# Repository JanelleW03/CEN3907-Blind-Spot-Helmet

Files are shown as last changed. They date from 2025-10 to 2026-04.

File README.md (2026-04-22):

# CEN4908-Blind-Spot-Helmet
Urban cyclists face safety risks from traffic and limited visibility. Traditional helmets protect the head but don’t enhance awareness. The Blind Spot Helmet uses radar-based detection and haptic feedback to alert riders of nearby vehicles in real time, improving safety for daily commuters on busy streets.

At a high level, our current architecture for this project is as follows. We utilize a Raspberry Pi 4 to poll two LiDAR sensors and interpret if there are any objects present within a predetermined range that could pose a risk to the user. If the LiDARs identify a potentially dangerous object, a haptic feedback sensor will be activated on the side that the object was detected to alert the user of its presence.

# Completed Work
We developed fully functioning code for the Pi 4 that polls the LiDAR sensors and successfully triggers haptic feedback on the side where an object was detected. 

In parallel, we are working on an implementation for the Raspberry Pi Pico, which is much more portable and consumes less power. At this point, we are currently testing LiDAR integration with Pico-specific code.

As for physical components within the project, we have gone through many iterations of 3d modules to house our system. The current one is robust and houses the Raspberry Pi as well as the sensors connected to it, with cutouts for charging and wiring.

# Known Bugs
The only main bug we have for our design at the moment is due to the physical connections between Raspberry Pi and sensors. Because we haven't soldered connections, as we are still testing multiple systems, our wiring is liable to disconnections during movement testing. This will be fixed once we have finalized our design and implement permanent connections.

# Onshape Design of Helmet Module
Copy and past this link into your browser to view:
https://cad.onshape.com/documents/718453d0fac994bf19ba09c7/w/0e19fb7305c1e5489b3984cd/e/3690a92add8a8350898fd115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

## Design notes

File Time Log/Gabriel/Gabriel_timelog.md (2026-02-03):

# Gabriel Timelog for Design II

## 01/19 - Team Meeting
### 2 hrs
- Discussed plan for the semester
- Divided work for the alpha build
- I was tasked with getting us back to where we were last semester, since we had our work erased and had a fresh sd card for the pi
- Initial environment setup for the pi

## 01/20 - Pi ML Camera Debug Session
## 5 hrs
- Had this debug session to get us back to where we were last semester
- Found out that there were some bugs regarding versions of different requirements for the ML camera script
- The most pressing issue was numpy version, which took me a while to figure out
- Removed custom numpy installation from python venv and defaulted to the default numpy system installation (version 1.19.5)

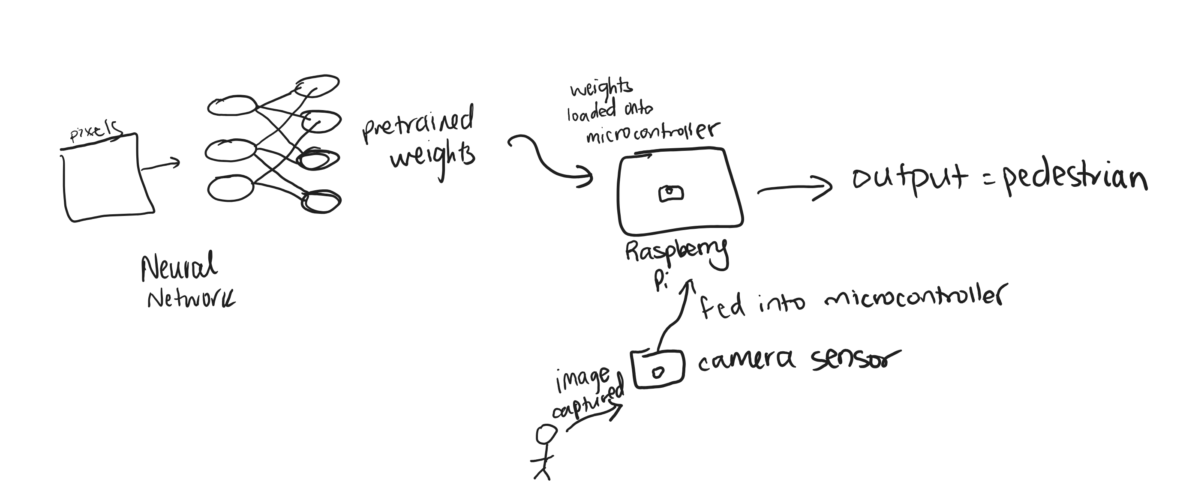
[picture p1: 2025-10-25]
cv_design.png

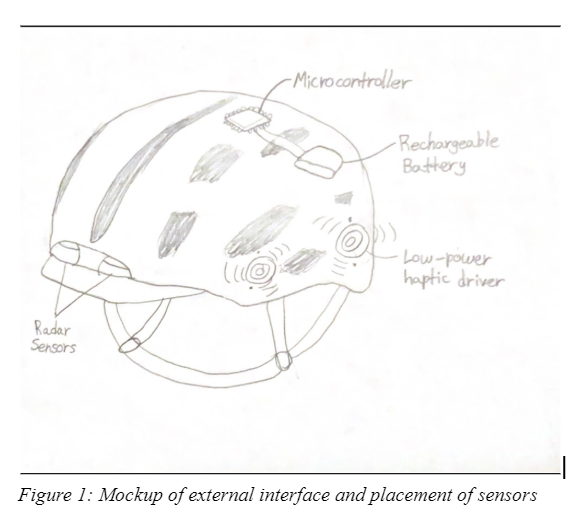
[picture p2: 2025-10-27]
Helmet Mockup.png

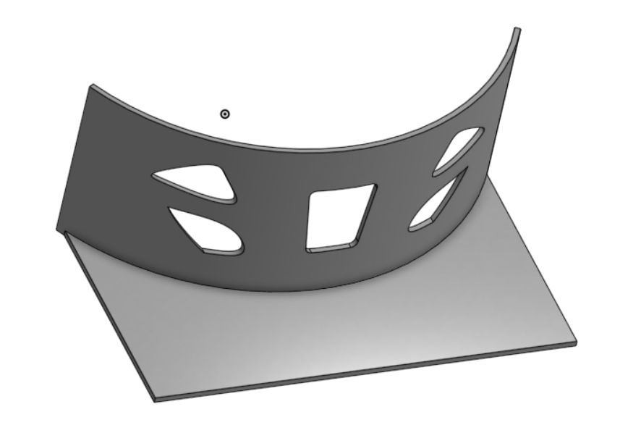
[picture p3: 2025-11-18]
Helmet Module Prototype.png

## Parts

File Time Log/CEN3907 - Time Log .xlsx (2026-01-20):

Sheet: Emily
Date | Time In | Time Out | Description of Work | Total Time
2025-10-01 | 0.4583333333 | 0.6458333333 | Research on components, primarily microprocessor and camera sensor | 4
2025-10-02 | 0.5833333333 | 0.7083333333 | Research on similar projects and integration techniques | 3
2025-10-07 | 0.4791666667 | 0.5 | Check in meeting 1, discussed design draft | 0.5
2025-10-09 | 0.5 | 0.5416666667 | Discussion with team on feedback from design draft, ideas on how to implement | 1
2025-10-14 | 0.4791666667 | 0.5208333333 | Check in meeting 2, discussed improvements for final design plan | 0.5
2025-10-17 | 0.5416666667 | 0.625 | Team meeting, compiled research on possible components, discussed | 2 | 46
2025-10-23 | 0.4791666667 | 0.5208333333 | Check in meeting 3, reviewed possible parts list | 1
2025-10-23 | 0.6666666667 | 0.7083333333 | Reviewed tinkercad for pre alpha build | 1
2025-10-24 | 0.5416666667 | 0.6666666667 | Researched haptic feedback articles to address user friendliness | 3
2025-10-25 | 0.625 | 0.7708333333 | Created simple CNN for car detection | 3.5
2025-11-04 | 23:30:00 | 13:00:00 | Check in meeting 5, ordered Raspberry Pi, camera attachment for Raspberry Pi, and webcam in case; discussed plan to meet for Raspberry Pi and camera setup | 1.5
2025-11-07 | 13:00:00 | 16:00:00 | Gathered materials; set up Raspberry Pi and camera module; created simple script to make sure pictures/videos could be taken | 3
2025-11-11 | 12:30:00 | 16:00:00 | Met with team and emailed stakeholder in lieu of Check in meeting 6; trained and tested ML model for vehicle image dataset | 3.5
2025-11-13 | 23:00:00 | 15:30:00 | Met with team and started working on the Onshape prototype for the helmet attachment. | 4.5
2025-11-13 | 18:00:00 | 20:00:00 | Worked on the documentation for the Prototype Report | 2
2025-11-14 | 14:30:00 | 17:30:00 | continued working on the onshape prototype | 3
2025-11-15 | 11:00:00 | 15:00:00 | finished working on the OnShape Prototype | 4
2025-11-16 | 13:30:00 | 17:00:00 | Worked on the documentation for the Prototype Report | 3.5
2025-11-16 | 21:30:00 | 23:00:00 | Worked on the documentation for the Prototype Report | 1.5

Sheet: Gabriel
Date | Time In | Time Out | Description of Work | Time
2025-10-01 | 0.5416666667 | 0.6666666667 | Researched possible parts that can be used in our design | 3
2025-10-03 | 0.375 | 0.4375 | Looked into haptic sensors/piezos and what could fit our product | 1.5
2025-10-07 | 0.4791666667 | 0.5 | Check in meeting 1, discussed design draft | 0.5
2025-10-09 | 0.5 | 0.5416666667 | Discussion with team on feedback from design draft, ideas on how to implement | 1
2025-10-10 | 0.5833333333 | 0.7083333333 | Began studying ML via online tutorials and youtube videos | 3
2025-10-12 | 0.7083333333 | 0.75 | Researched different cameras that we could use for ML | 1
2025-10-14 | 0.4791666667 | 0.5208333333 | Check in meeting 2, discussed improvements for final design plan | 1 | Total Time
2025-10-15 | 0.7083333333 | 0.8541666667 | Continued studying basic ML for the camera portion of our design | 3.5
2025-10-17 | 0.5416666667 | 0.6666666667 | Team meeting, compiled research on possible components, discussed | 3 | 46.5
2025-10-20 | 0.6666666667 | 0.7708333333 | Further researched ML for camera vision | 2.5
2025-10-23 | 0.4791666667 | 0.5208333333 | Check in meeting 3, reviewed possible parts list | 1
2025-10-25 | 18:00:00 | 20:30:00 | Researched object detection examples in Raspberry Pi as well as pre-trained models (Tensorflow) | 2.5
2025-10-28 | 11:00:00 | 12:30:00 | Check in meeting 4; afterwards discussed purchase of components | 1.5
2025-11-02 | 17:00:00 | 19:00:00 | Meeting with team, discussed work assignments and researched technical work to be completed | 2
2025-11-04 | 11:00:00 | 12:30:00 | Check in meeting 5; ordered Raspberry Pi, camera, and haptic sensors | 1.5
2025-11-07 | 11:00:00 | 13:00:00 | Set up radar sensor with Arduino; got it to detect presence | 3
2025-11-07 | 13:00:00 | 16:00:00 | Set up Raspberry Pi OS, configured camera, and took photos and videos with it to assess functionality | 3
2025-11-11 | 13:00:00 | 16:00:00 | Met with team; mostly worked on configuring remote access to Raspberry Pi via SSH | 3
2025-11-13 | 0.4895833333 | 0.7708333333 | Configured object detection on camera and got it working | 6.75
2025-11-17 | 0.4166666667 | 0.5104166667 | Created script to automatically set up camera on new raspi images | 2.25

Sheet: Devika
Date | Time In | Time Out | Description of Work | Total Time
2025-10-01 | 0.4583333333 | 0.6041666667 | Research on components, primarily microprocessor and camera sensor | 3.5
2025-10-02 | 0.5833333333 | 0.7083333333 | Research on textbook about computer vision with Raspberry Pi, read some of book | 3
2025-10-07 | 0.4791666667 | 0.5 | Check in meeting 1, discussed design draft | 0.5
2025-10-09 | 0.5 | 0.5416666667 | Discussion with team on feedback from design draft, ideas on how to implement | 1
2025-10-14 | 0.4791666667 | 0.5208333333 | Check in meeting 2, discussed improvements for final design plan | 0.5
2025-10-17 | 0.5416666667 | 0.6666666667 | Team meeting, compiled research on possible components, discussed | 3 | Total Time:
2025-10-23 | 0.4791666667 | 0.5208333333 | Check in meeting 3, reviewed possible parts list | 1 | 47.25
2025-10-23 | 0.6666666667 | 0.7083333333 | Reviewed tinkercad for pre alpha build | 1
2025-10-24 | 0.5416666667 | 0.6666666667 | Researched and found Kaggle dataset for car detection, yolo code for image recognition | 3
2025-10-25 | 0.625 | 0.7708333333 | Created simple CNN for car detection | 3.5
2025-10-28 | 11:00:00 | 12:30:00 | Check in meeting 4, discussed with team after to purchase parts | 1.5
2025-11-02 | 17:00:00 | 19:00:00 | Meeting with team, discussed work assignments and researched technical work to be completed | 2
2025-11-04 | 11:00:00 | 12:30:00 | Check in meeting 5, ordered Raspberry Pi, camera, and haptic sensors | 1.5
2025-11-07 | 11:00:00 | 13:00:00 | Set up radar sensor with Arduino, wrote code to communicate through UART to detect presence | 3
2025-11-07 | 13:00:00 | 16:00:00 | Set up Raspberry Pi OS, configured camera, wrote Python script to record videos and take photos to prove camera functionality | 3
2025-11-09 | 19:00:00 | 22:00:00 | Updated the CNN, used a simpler architecture, wrote code to preprocess image dataset and trained model | 3
2025-11-11 | 10:00:00 | 11:30:00 | Wrote email in lieu of check in 6, updating professor on work the team completed and will present for prototype | 1.5
2025-11-11 | 13:00:00 | 16:00:00 | Met with team to continue working on prototype report, slides, and found example model to download on Raspberry Pi | 3
2025-11-11 | 17:00:00 | 19:00:00 | Researched converting Pytorch CNN model to tflite format for Raspberry Pi, started writing code to convert model | 2
2025-11-13 | 11:45:00 | 14:00:00 | Connected radar sensor to rest of sensors (LED, piezo, and haptic), updated Arduino code to have total interaction | 2.25
2025-11-13 | 14:00:00 | 15:30:00 | Updated Raspberry Pi OS to be compatible with popular ML models, downloaded example model for object detection | 1.5
2025-11-16 | 15:00:00 | 18:00:00 | Double checked functionality of Raspberry Pi with downloaded model, and radar sensor-piezo setup, practice demo | 3

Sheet: Janelle
Date | Start Time | End Time | Duration | Summary of Tasks Completed
2025-10-01 | 0.4583333333 | 0.6041666667 | 3.50 | Research on components, primarily microprocessor and camera sensor
2025-10-02 | 0.5833333333 | 0.7083333333 | 3.00 | Research on textbook about computer vision with Raspberry Pi
2025-10-07 | 0.4791666667 | 0.5208333333 | 1.00 | Check in meeting 1, discussed design draft
2025-10-09 | 0.5 | 0.5416666667 | 1.00 | Discussion with team on feedback from design draft, ideas on how to implement
2025-10-14 | 0.4791666667 | 0.5208333333 | 1.00 | Check in meeting 2, discussed improvements for final design plan
2025-10-17 | 0.5416666667 | 0.6666666667 | 3.00 | Team meeting, compiled research on possible components, discussed
2025-10-23 | 0.4791666667 | 0.5625 | 2.00 | Check in meeting 3, reviewed possible parts list
2025-10-23 | 0.7916666667 | 0.875 | 4.00 | Designed and built tinkercad demo with code
2025-10-23 | 0.6666666667 | 0.75 | 2 | Reviewed tinkercad for pre alpha build
2025-10-24 | 0.5416666667 | 0.6666666667 | 3 | Researched and found Kaggle dataset for car detection, yolo code for image recognition
2025-10-25 | 0.625 | 0.7708333333 | 3.5 | Created simple CNN for car detection
2025-10-28 | 11:00:00 | 12:30:00 | 1.5 | Check in meeting 4, discussed with team after to purchase parts
2025-11-02 | 17:00:00 | 19:00:00 | 2 | discussed work assignments and any parts we still need to order
2025-11-04 | 11:00:00 | 12:30:00 | 1.5 | Check in meeting 5, ordered Raspberry Pi, camera, and haptic sensors
2025-11-04 | 11:00:00 | 13:00:00 | 2.00 | team meeting, compiled research on possible components, discussed
2025-11-05 | 11:00:00 | 14:00:00 | 3 | team meeting to test radar sensor
2025-11-11 | 10:00:00 | 11:30:00 | 1.5 | Wrote email in lieu of check in 6, updating stakeholder on work the team completed and will present for prototype
2025-11-11 | 15:00:00 | 17:00:00 | 2.00 | integrated radar with distance sensor
2025-11-14 | 10:00:00 | 12:00:00 | 2.00 | switched radar sensor serial so that it works faster and detects more accurate with the arduino
2025-11-15 | 10:00:00 | 12:00:00 | 2 | worked with arduino and make the connections more organized to a smaller breadboard
2025-11-16 | 15:00:00 | 17:00:00 | 2.00 | practiced demo and slides for presentation
 |  |  | 46.50

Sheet: Ana
Date | Time In | Time Out | Description of Work | Total Time
2025-10-01 | 19:30:00 | 22:00:00 | Researched existing solutions to cycling problem and ways to differentiate solution with our product | 2.5
2025-10-02 | 17:30:00 | 21:00:00 | Researched hardware components for helmet (potential sensors) | 2.5
2025-10-05 | 12:00:00 | 15:30:00 | Researched CNN model for image recognition and potential datasets to use for image detection | 3.5
2025-10-07 | 11:30:00 | 12:00:00 | Check in meeting 1, discussed design draft | 0.5
2025-10-09 | 12:00:00 | 13:00:00 | Discussion with team on feedback from design draft, ideas on how to implement | 1
2025-10-14 | 11:30:00 | 12:30:00 | Check in meeting 2, discussed improvements for final design plan | 0.5
2025-10-17 | 13:00:00 | 16:00:00 | Team meeting, compiled research on possible components, discussed | 3 | Total Time: | 46
2025-10-17 | 16:00:00 | 17:30:00 | Researched and added more components to possible component list individually | 1.5
2025-10-23 | 11:30:00 | 12:30:00 | Check in meeting 3, reviewed possible parts list | 1
2025-10-23 | 15:00:00 | 17:00:00 | Narrowed down parts list for pre-alpha build, reviewed Tinkercad and Arduino implementation | 2
2025-10-25 | 18:00:00 | 20:00:00 | Reviewed CNN code and researched ways to expand it for the prototype | 2
2025-10-28 | 23:30:00 | 12:00:00 | Check in meeting 4, ordered radar sensor and discussed ordering other parts | 0.5
2025-11-02 | 17:00:00 | 19:00:00 | Meeting with team, discussed work assignments and researched technical work to be completed | 2
2025-11-04 | 23:30:00 | 13:00:00 | Check in meeting 5, ordered Raspberry Pi, camera attachment for Raspberry Pi, and webcam in case; discussed plan to meet for Raspberry Pi and camera setup | 1.5
2025-11-07 | 13:00:00 | 16:00:00 | Gathered materials; set up Raspberry Pi and camera module; created simple script to make sure pictures/videos could be taken | 3
2025-11-10 | 13:00:00 | 16:30:00 | Researched more ways to improve ML model before testing (hyperparameters, etc.) | 3.5
2025-11-11 | 13:00:00 | 16:00:00 | Met with team and emailed stakeholder in lieu of Check in meeting 6; trained and tested ML model for vehicle image dataset | 3
2025-11-13 | 12:00:00 | 15:00:00 | Met with team and started working on the Onshape prototype for the helmet attachment. | 3
2025-11-14 | 15:30:00 | 17:30:00 | Sketched out attachable helmet module for the chosen helmet; reviewed Onshape tools and began creating module prototype in Onshape | 2
2025-11-15 | 12:00:00 | 15:30:00 | Completed 3D modeling of helmet module prototype on Onshape | 3.5
2025-11-16 | 14:00:00 | 18:00:00 | Ensured all components were functioning individually and together for demonstration; practiced prototype presentation | 4

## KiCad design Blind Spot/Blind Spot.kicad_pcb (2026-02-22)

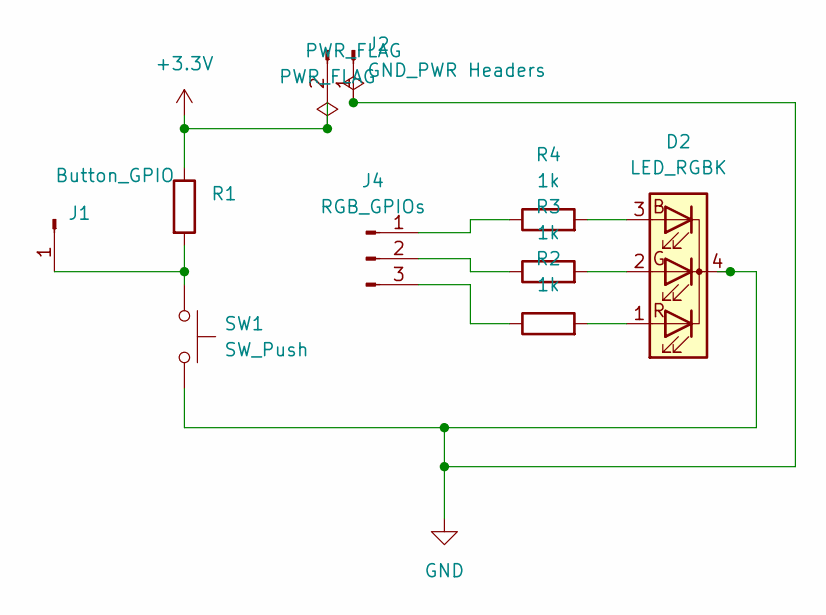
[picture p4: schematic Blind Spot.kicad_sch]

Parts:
D2: LED_RGBK; LED_D5.0mm-4_RGB
J1: Button_GPIO; PinHeader_1x03_P2.54mm_Vertical
J2: GND_PWR Headers; PinHeader_1x02_P2.54mm_Vertical
J4: RGB_GPIOs; PinHeader_1x03_P2.54mm_Vertical
R1, R2, R3, R4: 1k; R_0805_2012Metric
SW1: SW_Push; SW_PUSH_6mm

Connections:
+3.3V: J2.2, R1.1
GND: D2.4 (K), J2.1, SW1.2
unnamed: D2.3 (BA), R4.2
unnamed: D2.2 (GA), R3.2
unnamed: D2.1 (RA), R2.2
unnamed: J1.1, R1.2, SW1.1
unnamed: J4.1, R4.1
unnamed: J4.2, R3.1
unnamed: J4.3, R2.1

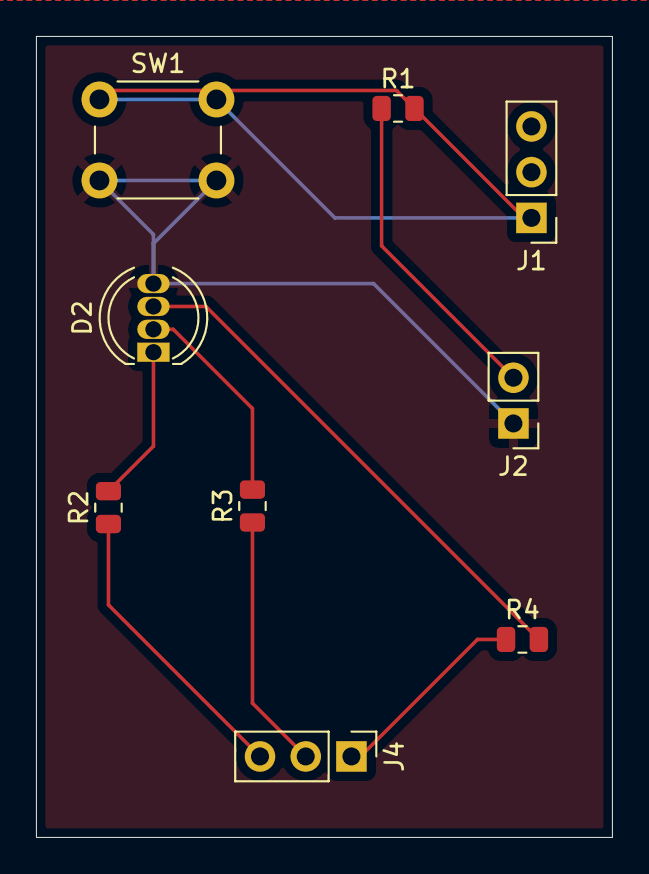
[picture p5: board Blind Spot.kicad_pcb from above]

Board: 2 copper layers, 32.0 x 44.5 mm, 9 parts (0 on the bottom side), 9 nets.

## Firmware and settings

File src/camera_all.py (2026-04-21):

from gpiozero import RGBLED, PWMOutputDevice, Button, DistanceSensor
from time import sleep
import serial, time
import numpy as np

import cv2
from picamera2 import Picamera2
from tflite_support.task import core
from tflite_support.task import processor
from tflite_support.task import vision

THREAD_NUM = 4
DISPLAY_WIDTH = 1280
DISPLAY_HEIGHT = 720
DEFAULT_MODEL = 'efficientdet_lite0.tflite'
CORAL_MODEL = 'efficientdet_lite0_edgetpu.tflite'
FPS_POS = (20, 60)
FPS_FONT = cv2.FONT_HERSHEY_SIMPLEX
FPS_HEIGHT = 1.5
FPS_WEIGHT = 3
FPS_COLOR = (255, 0, 0)
FPS_AVG_FRAME_COUNT = 10
TRIGGER_CLASSES = {"car", "motorcycle", "bus", "truck", "person"}

# UD = DistanceSensor(echo=17, trigger=4, max_distance=4)
motor1 = PWMOutputDevice(27)
motor2 = PWMOutputDevice(26) 
led = RGBLED(22, 23, 24, active_high=False)
button = Button(17)
button_state = False
counter = 0

sleep(2)

def calculate_vibration(distance):
        vibration = (((distance - 0.02) * -1) / (4 - 0.02)) + 1
        return max(0.0, min(1.0, vibration))

def calculate_distance(duration):
        speed = 343
        distance = (speed * duration / 2)
        return distance

ser = serial.Serial("/dev/serial0", 115200, timeout=0)
ser2 = serial.Serial("/dev/ttyAMA1", 115200, timeout=0)

# Get image from the camera module
picam2 = Picamera2()
picam2.preview_configuration.main.size = (DISPLAY_WIDTH, DISPLAY_HEIGHT)
picam2.preview_configuration.main.format = 'RGB888'
picam2.preview_configuration.main.align()
picam2.configure("preview")
picam2.start()

model = DEFAULT_MODEL

# Initialize the object detection model
base_options = core.BaseOptions(
        file_name=model, use_coral=False, num_threads=THREAD_NUM)
detection_options = processor.DetectionOptions(
        max_results=4, score_threshold=0.3)
options = vision.ObjectDetectorOptions(
        base_options=base_options, detection_options=detection_options)
detector = vision.ObjectDetector.create_from_options(options)

def read_tfluna_data1():
    start = time.time()
    while time.time() - start < 0.1:
        counter = ser.in_waiting
        if counter > 8:
            bytes_serial = ser.read(9)
            ser.reset_input_buffer()

            if bytes_serial[0] == 0x59 and bytes_serial[1] == 0x59:
                distance = bytes_serial[2] + bytes_serial[3]*256
                strength = bytes_serial[4] + bytes_serial[5]*256
                temperature = bytes_serial[6] + bytes_serial[7]*256
                temperature = (temperature/8.0) - 256.0
                ##print(distance)
                return distance/100.0, strength, temperature
    return None

def read_tfluna_data2():
    start = time.time()
    while time.time() - start < 0.1:
        counter = ser2.in_waiting
        if counter > 8:
            bytes_serial = ser2.read(9)
            ser2.reset_input_buffer()

            if bytes_serial[0] == 0x59 and bytes_serial[1] == 0x59:
                distance = bytes_serial[2] + bytes_serial[3]*256
                strength = bytes_serial[4] + bytes_serial[5]*256
                temperature = bytes_serial[6] + bytes_serial[7]*256
                temperature = (temperature/8.0) - 256.0
                ##print(distance)
                return distance/100.0, strength, temperature
    return None

if ser.isOpen() == False:
        ser.open()

if ser2.isOpen() == False:
        ser2.open()

def toggle_system():
        global button_state
        button_state = not button_state
        print("System ON" if button_state else "System OFF")

# button management
#button.when_released = toggle_system
led.color = (0, 0, 1)
while True:
    #distanceUD = UD.distance * 4

    distanceTF1, strength1, temp1 = read_tfluna_data1()
    distanceTF2, strength2, temp2 = read_tfluna_data2()
    vibration1 = calculate_vibration(distanceTF1)
    vibration2 = calculate_vibration(distanceTF2)

    if distanceTF1 is None:
        print(f"TFLuna1 timeout")
        continue

    if distanceTF2 is None:
        print(f"TFLuna2 timeout")
        continue

    if True: # button is pressed to turn on the system
        #print("System running")
        #print(f"Ultrasonic: {distanceUD:.3f} m | TF-Luna: {distanceTF:.3f} m")
        #print("vibration: ", vibration)
        print("distance1: ",  distanceTF1, "distance2: ", distanceTF2)
        #label = "cat"
        #led.color = (0, 0, 1)
        if distanceTF1 < 9.0 and distanceTF1 > 2.0: # distanceUD < 0.5 and (for distance sensor reliability)
             # Camera checking code here
             image = picam2.capture_array()
             counter += 1
             image = cv2.flip(image, -1)
             # Convert the image from BGR to RGB as required by the TFLite model
             image_RGB = cv2.cvtColor(image, cv2.COLOR_BGR2RGB)

             # Create a TensorImage object from  the RGB image
             image_tensor = vision.TensorImage.create_from_array(image_RGB)

             # Run object detection estimation using the model
             detections = detector.detect(image_tensor)

             if detections.detections:
                  for det in detections.detections:
                        category = det.categories[0]
                        label = category.category_name
                        score = category.score
                
                        print(f"Detected: {label} ({score:.2f}) ")
                        if label in TRIGGER_CLASSES:
                             motor1.value = vibration1
                             led.color = (0, 1, 0) # Green
                             print("lidar1 detection")
                             break
                        else:
                             motor1.value = 0
                             led.color = (0, 0, 1)
                  continue

        else:
            led.color = (0, 0, 1)
            motor1.value = 0

        if distanceTF2 < 9.0 and distanceTF2 > 2.0:
              # Camera checking code here
             image = picam2.capture_array()
             counter += 1
             image = cv2.flip(image, -1)
             # Convert the image from BGR to RGB as required by the TFLite model
             image_RGB = cv2.cvtColor(image, cv2.COLOR_BGR2RGB)

             # Create a TensorImage object from  the RGB image
             image_tensor = vision.TensorImage.create_from_array(image_RGB)

             # Run object detection estimation using the model
             detections = detector.detect(image_tensor)

             if detections.detections:
                  for det in detections.detections:
                        category = det.categories[0]
                        label = category.category_name
                        score = category.score
                
                        print(f"Detected: {label} ({score:.2f}) ")
                        if label in TRIGGER_CLASSES:
                             motor2.value = vibration1
                             led.color = (0, 1, 0) # Green
                             print("lidar2 detection")
                             break
                        else:
                             motor2.value = 0
                             led.color = (0, 0, 1)
                  continue
        else:
            motor2.value = 0
            led.color = (0, 0, 1)
            
    else:
        print("System Idle")
        led.color = (1, 0, 0) # Red when off
        motor1.value = 0
        motor2.value = 0

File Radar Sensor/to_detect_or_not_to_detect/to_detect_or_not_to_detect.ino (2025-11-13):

#include <AltSoftSerial.h>
#include "DFRobot_mmWave_Radar.h"

// This code demonstrates a faster radar sensor detection with the use of AltSoftSerial instead of the SoftwareSerial that was used in the original example code
// also the built-in LED should be blinking as long as the sensor received power 
// The TX and DX have to be RX=D9 and TX=D8 becuase of this serial
// Also another important thing to mention the baud has to 115200

// Important things to note:
// the radar can only sense movement around it (aka if the sensor is moving but there is nothing around it won't detect anything)
// the arduino seems to consistrently disconnect, have tried switching cables and switching arduinos with little luck

AltSoftSerial mySerial;              // RX=D8, TX=D9
DFRobot_mmWave_Radar sensor(&mySerial);

void setup() {
  pinMode(LED_BUILTIN, OUTPUT);
  Serial.begin(115200);        
  mySerial.begin(115200);

  //sensor.factoryReset();
  //sensor.DetRangeCfg(0, 1);
  //sensor.OutputLatency(0, 0);
}

void loop() {
  int val = sensor.readPresenceDetection();
  digitalWrite(LED_BUILTIN, val ? HIGH : LOW);
  Serial.print("value ");
  Serial.println(val);
  delay(50);
}

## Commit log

2025-10-23 Add Pre-Alpha build code for ultrasonic distance sensor
    Code for tinkercad pre-alpha build prototype. The parts used here will not be used in the future and we will most likely use a raspberry pi. This is purely meant to demonstrates the core of our proje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
2025-11-07 arduino code changes
2025-11-07 faster radar sensor
2025-11-13 RX and TX confusion fixed
    [to_detect_or_not_to_detect.ino]
2025-11-15 Helmet Module Prototype made on Onshape
    https://cad.onshape.com/documents/718453d0fac994bf19ba09c7/w/0e19fb7305c1e5489b3984cd/e/772e344e4bcf35f5efbb1f72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
2025-11-16 Create script to setup camera
2025-11-18 Add setup script for ML camera model
2026-01-20 raspberry pi sensor and haptic test
2026-01-20 time log from sem 1 & new logs
    [CEN3907 - Time Log .xlsx]
2026-01-22 LiDar test & UART functionality
2026-01-26 Add meeting notes for 3D model housing discussion
2026-01-26 fixed alpha with no known bugs
    [alphaBuild.py]
2026-01-29 lidar with headless camera detection
2026-02-02 code with button UI
2026-02-02 finish UD and lidar code for demo
2026-02-03 button code
2026-02-10 update camera and haptic code
2026-02-12 LED UI and UD removed
2026-02-12 RGB LED edits
2026-02-17 Update alphaBuild.py
    Updated based on working Raspberry Pi code
2026-02-17 Update alphaBuild.py
    Changed some GPIO pin assignments for ease of access on physical module
2026-02-17 code for two lidars, and changed original alphaBuild.py to check for longer distances
2026-02-17 PCB files
    The main pcb files to be reviewed are the blind spot.kicad_sch and the blind spot.kicad_pcb. all of the other files are the production files that come from building the gerber plot
    [Blind Spot-B_Cu.gbr, Blind Spot-B_Mask.gbr, Blind Spot-B_Silkscreen.gbr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]
2026-02-17 Add entries for PCB work on 2/13 and 2/17
2026-02-17 Revise PCB entry for 2/13 with design changes
    Updated time log entry for 2/13 to include design changes for GPIO ports.
2026-02-17 Update time log with recent meeting notes and tasks
    Added new entries for meetings and progress updates on PCB work.
2026-02-19 Zipped Gerber files
    This zipped folder has everything we need to send the pcb to get produced
2026-02-19 implement functioning code to test LIDAR with Pico
2026-02-21 Revise README to update project architecture and progress
    Updated project details to reflect changes in architecture and functionality, including the use of LiDAR sensors and Raspberry Pi integration.
2026-02-22 working LED
2026-02-22 LED edits
2026-03-02 camera with led/lidar/button code:
2026-04-21 added helmet code
    [pyvenv.cfg]
2026-04-21 deleted object-detect
    [pyvenv.cfg]
